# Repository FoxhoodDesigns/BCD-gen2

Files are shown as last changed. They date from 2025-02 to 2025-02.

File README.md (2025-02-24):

# Binary Clock 2
A successor to my very first electronics project i made when I was 16y old: A Binary Clock using only discrete logic (4000/74HC series)
Re-imagined using the skills I learned over time to turn it from a barely working beginner's project. To something I honestly could sell as a Soldering Kit.
Complete with fully worked out Power design that can safely be run off a Li-Ion Battery.

For more information. Please visit the Hackaday IO journal that is being written alongside this project that goes into depth on the reverse engineering of the original and iterating on its design:
https://hackaday.io/project/197273-4000-series-bcd-clock-g2

# NOTE ON PCB Layout:
This project is designed to be a little more artistic in appearance with the PCB visible to the outside world.
As such the PCB is intended to be made using a transparent Solder-mask that renders the copper visible. With the Front side lacking a Copper-pour and using rounded traces.
Please refer to OSH-Park's "After Dark" service for examples on how such PCBs tend to look.

# Current Status:
Still in mid Layout. Though should be ready for having its first set built once I finish it. Trying to figure out what to do with the Blank spot on the front in regards of copper. Maybe A Image of some kind?

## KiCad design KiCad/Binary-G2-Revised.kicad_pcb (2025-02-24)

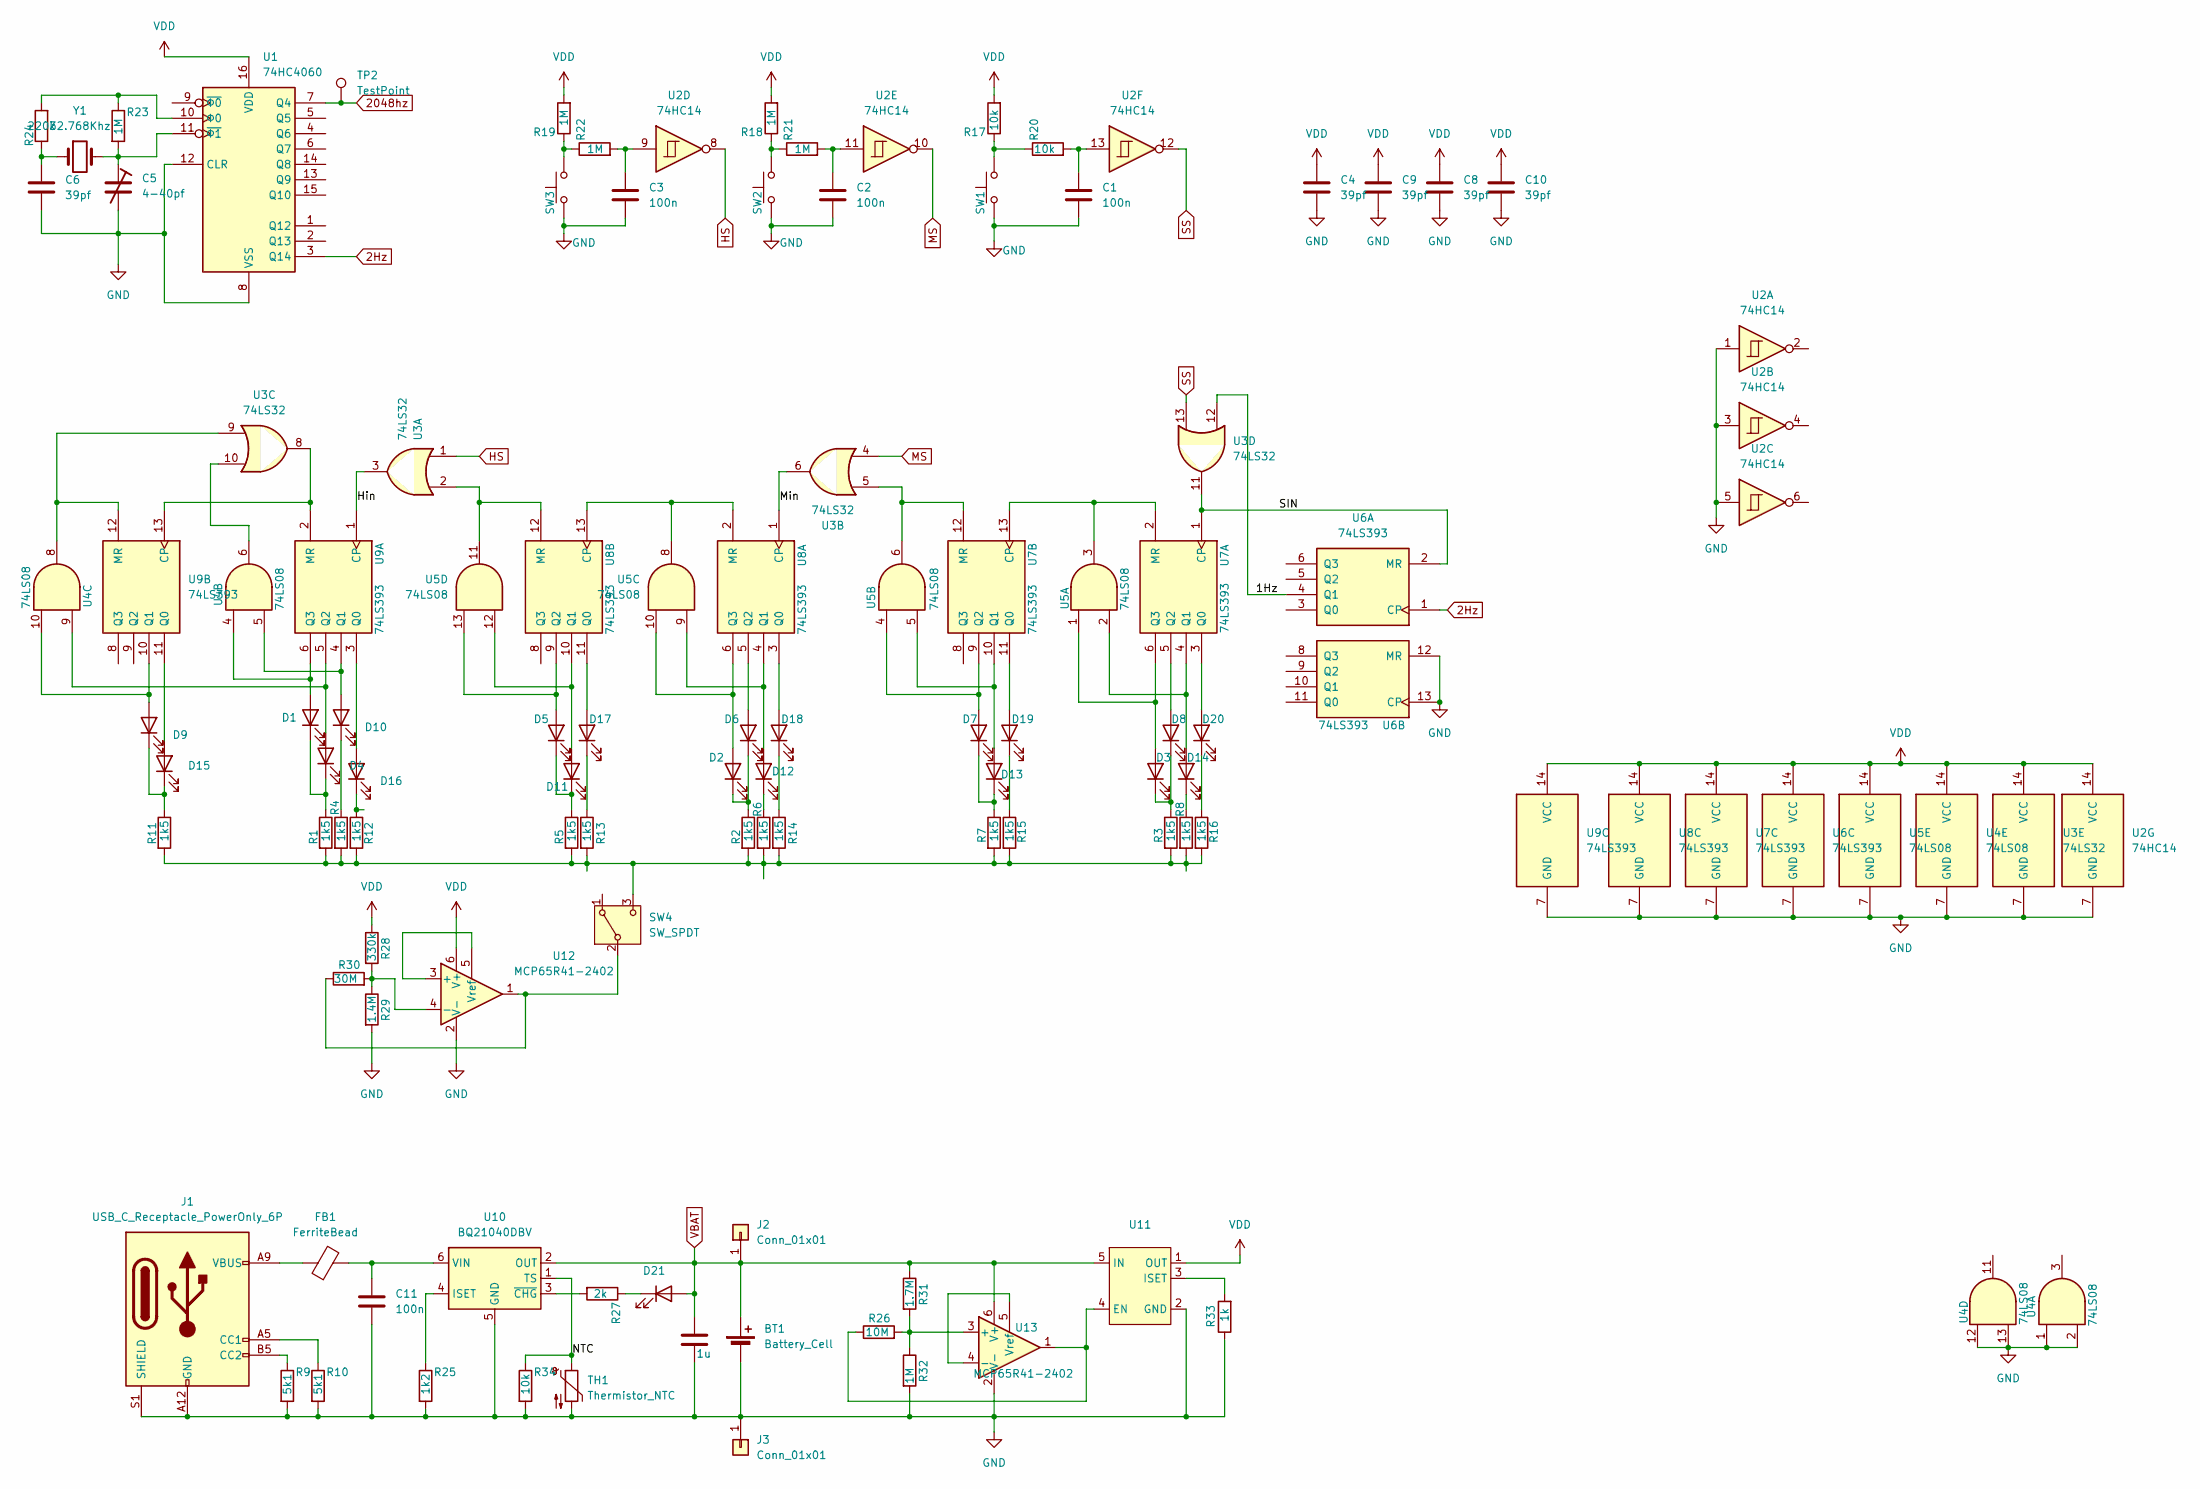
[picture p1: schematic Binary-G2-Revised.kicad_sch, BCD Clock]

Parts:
BT1: Battery_Cell
C1, C2, C3, C11: 100n; C_0805_2012Metric_Pad1.18x1.45mm_HandSolder
C4, C6, C8, C9, C10: 39pf; C_0805_2012Metric_Pad1.18x1.45mm_HandSolder
C5: 4-40pf; C_Trimmer_Murata_TZY2
C7: 1u; C_0805_2012Metric_Pad1.18x1.45mm_HandSolder
D1, D2, D3, D4, D5, D6, D7, D8, D9, D10, D11, D12, D13, D14, D15, D16, D17, D18, D19, D20: LED; LED_1206_3216Metric_Pad1.42x1.75mm_HandSolder
D21: LED; LED_0805_2012Metric_Pad1.15x1.40mm_HandSolder
FB1: FerriteBead; L_0805_2012Metric_Pad1.15x1.40mm_HandSolder
J1: USB_C_Receptacle_PowerOnly_6P; USB_C_Receptacle_USB4130
J2, J3: Conn_01x01; SolderWirePad_1x01_SMD_1x2mm
R1, R2, R3, R4, R5, R6, R7, R8, R11, R12, R13, R14, R15, R16: 1k5; R_0805_2012Metric_Pad1.20x1.40mm_HandSolder
R9, R10: 5k1; R_0805_2012Metric_Pad1.20x1.40mm_HandSolder
R17, R20, R34: 10k; R_0805_2012Metric_Pad1.20x1.40mm_HandSolder
R18, R19, R21, R22, R23, R32: 1M; R_0805_2012Metric_Pad1.20x1.40mm_HandSolder
R24: 220k; R_0805_2012Metric_Pad1.20x1.40mm_HandSolder
R25: 1k2; R_0805_2012Metric_Pad1.20x1.40mm_HandSolder
R26: 10M; R_0805_2012Metric_Pad1.20x1.40mm_HandSolder
R27: 2k; R_0805_2012Metric_Pad1.20x1.40mm_HandSolder
R28: 330k; R_0805_2012Metric_Pad1.20x1.40mm_HandSolder
R29: 1.4M; R_0805_2012Metric_Pad1.20x1.40mm_HandSolder
R30: 30M; R_0805_2012Metric_Pad1.20x1.40mm_HandSolder
R31: 1.7M; R_0805_2012Metric_Pad1.20x1.40mm_HandSolder
R33: 1k; R_0805_2012Metric_Pad1.20x1.40mm_HandSolder
SW1, SW2, SW3: PTH_RA_7.4x4.3mm; SW_Push_1P1T_NO_Vertical_Wuerth_434133025816
SW4: SW_SPDT; SW_SPDT_PCM12
TH1: Thermistor_NTC; SolderWirePad_1x01_SMD_1x2mm
TP2: TestPoint; TestPoint_Pad_2.0x2.0mm
U1: 74HC4060; SO-16_3.9x9.9mm_P1.27mm
U2: 74HC14; SO-14_3.9x8.65mm_P1.27mm
U3: 74LS32; SO-14_3.9x8.65mm_P1.27mm
U4, U5: 74LS08; SO-14_3.9x8.65mm_P1.27mm
U6, U7, U8, U9: 74LS393; SO-14_3.9x8.65mm_P1.27mm
U10: BQ21040DBV; SOT-23-6
U11: SOT-23-5_HandSoldering
U12, U13: MCP65R41-2402; SOT-23-6
Y1: 32.768Khz; Crystal_C26-LF_D2.1mm_L6.5mm_Horizontal_1EP_style2

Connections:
2Hz: U1.3 (Q14), U6.1 (CP)
2048hz: TP2.1, U1.7 (Q4)
/1Hz: U3.12, U6.4 (Q1)
/Hin: U3.3, U9.1 (CP)
/Min: U3.6, U8.1 (CP)
/NTC: R34.1, TH1.1, U10.1 (TS)
/SIN: U3.11, U6.2 (MR), U7.1 (CP)
GND: BT1.2 (-), C1.2, C2.2, C3.2, C4.2, C5.2, C6.2, C7.2, C8.2, C9.2, C10.2, C11.2, J1.A12 (GND), J1.B12 (GND), J1.S1 (SHIELD), J3.1, R9.2, R10.2, R25.2, R29.2, R32.2, R33.1, R34.2, SW1.1, SW2.1, SW3.1, TH1.2, U1.8 (VSS), U1.12 (CLR), U2.1, U2.3, U2.5, U2.7 (GND), U3.7 (GND), U4.1, U4.2, U4.7 (GND), U4.12, U4.13, U5.7 (GND), U6.7 (GND), U6.12 (MR), U6.13 (CP), U7.7 (GND), U8.7 (GND), U9.7 (GND), U10.5 (GND), U11.2 (GND), U12.2 (V-), U13.2 (V-)
HS: U2.8, U3.1
MS: U2.10, U3.4
unnamed: C1.1, R20.2, U2.13
unnamed: C2.1, R21.2, U2.11
unnamed: C3.1, R22.2, U2.9
unnamed: C6.1, R24.1, Y1.1
unnamed: D1.2 (A), U4.4, U9.6 (Q3)
unnamed: D1.1 (K), D4.1 (K), R1.1
unnamed: D2.2 (A), U5.10, U8.6 (Q3)
unnamed: D2.1 (K), D6.1 (K), R2.1
unnamed: D3.2 (A), U5.1, U7.6 (Q3)
unnamed: D3.1 (K), D8.1 (K), R3.1
unnamed: D4.2 (A), U4.9, U9.5 (Q2)
unnamed: D5.2 (A), U5.13, U8.9 (Q2)
unnamed: D6.2 (A), U8.5 (Q2)
unnamed: D7.2 (A), U5.4, U7.9 (Q2)
unnamed: D8.2 (A), U7.5 (Q2)
unnamed: D9.2 (A), U4.10, U9.10 (Q1)
unnamed: D10.2 (A), U4.5, U9.4 (Q1)
unnamed: D10.1 (K), R4.1
unnamed: D11.2 (A), U5.12, U8.10 (Q1)
unnamed: D5.1 (K), D11.1 (K), R5.1
unnamed: D12.2 (A), U5.9, U8.4 (Q1)
unnamed: D12.1 (K), R6.1
unnamed: D13.2 (A), U5.5, U7.10 (Q1)
unnamed: D7.1 (K), D13.1 (K), R7.1
unnamed: D14.2 (A), U5.2, U7.4 (Q1)
unnamed: D14.1 (K), R8.1
unnamed: D15.2 (A), U9.11 (Q0)
unnamed: D9.1 (K), D15.1 (K), R11.1
unnamed: D16.2 (A), U9.3 (Q0)
unnamed: D16.1 (K), R12.1
unnamed: D17.2 (A), U8.11 (Q0)
unnamed: D17.1 (K), R13.1
unnamed: D18.2 (A), U8.3 (Q0)
unnamed: D18.1 (K), R14.1
unnamed: D19.2 (A), U7.11 (Q0)
unnamed: D19.1 (K), R15.1
unnamed: D20.2 (A), U7.3 (Q0)
unnamed: D20.1 (K), R16.1
unnamed: D21.1 (K), R27.1
unnamed: FB1.1, J1.A9 (VBUS), J1.B9 (VBUS)
unnamed: J1.A5 (CC1), R10.1
unnamed: J1.B5 (CC2), R9.1
unnamed: R17.1, R20.1, SW1.2
unnamed: R18.1, R21.1, SW2.2
unnamed: R19.1, R22.1, SW3.2
unnamed: R30.1, SW4.2 (B), U12.1
unnamed: R1.2, R2.2, R3.2, R4.2, R5.2, R6.2, R7.2, R8.2, R11.2, R12.2, R13.2, R14.2, R15.2, R16.2, SW4.3 (C)
unnamed: C5.1, R23.2, U1.11 (~Φ1), Y1.2
unnamed: R23.1, R24.2, U1.10 (Φ0)
unnamed: U3.10, U4.6
unnamed: U5.3, U7.2 (MR), U7.13 (CP)
unnamed: U3.5, U5.6, U7.12 (MR)
unnamed: U5.8, U8.2 (MR), U8.13 (CP)
unnamed: U3.2, U5.11, U8.12 (MR)
unnamed: U3.8, U9.2 (MR), U9.13 (CP)
unnamed: U3.9, U4.8, U9.12 (MR)
unnamed: R25.1, U10.4 (ISET)
unnamed: C11.1, FB1.2, U10.6 (VIN)
unnamed: R27.2, U10.3 (~CHG)
unnamed: R26.1, U11.4 (EN), U13.1
unnamed: R33.2, U11.3 (ISET)
unnamed: U12.3 (+), U12.5 (Vref)
unnamed: R28.2, R29.1, R30.2, U12.4 (-)
unnamed: R26.2, R31.2, R32.1, U13.3 (+)
unnamed: U13.4 (-), U13.5 (Vref)
SS: U2.12, U3.13
VBAT: BT1.1 (+), C7.1, D21.2 (A), J2.1, R31.1, U10.2 (OUT), U11.5 (IN), U13.6 (V+)
VDD: C4.1, C8.1, C9.1, C10.1, R17.2, R18.2, R19.2, R28.1, U1.16 (VDD), U2.14 (VCC), U3.14 (VCC), U4.14 (VCC), U5.14 (VCC), U6.14 (VCC), U7.14 (VCC), U8.14 (VCC), U9.14 (VCC), U11.1 (OUT), U12.6 (V+)

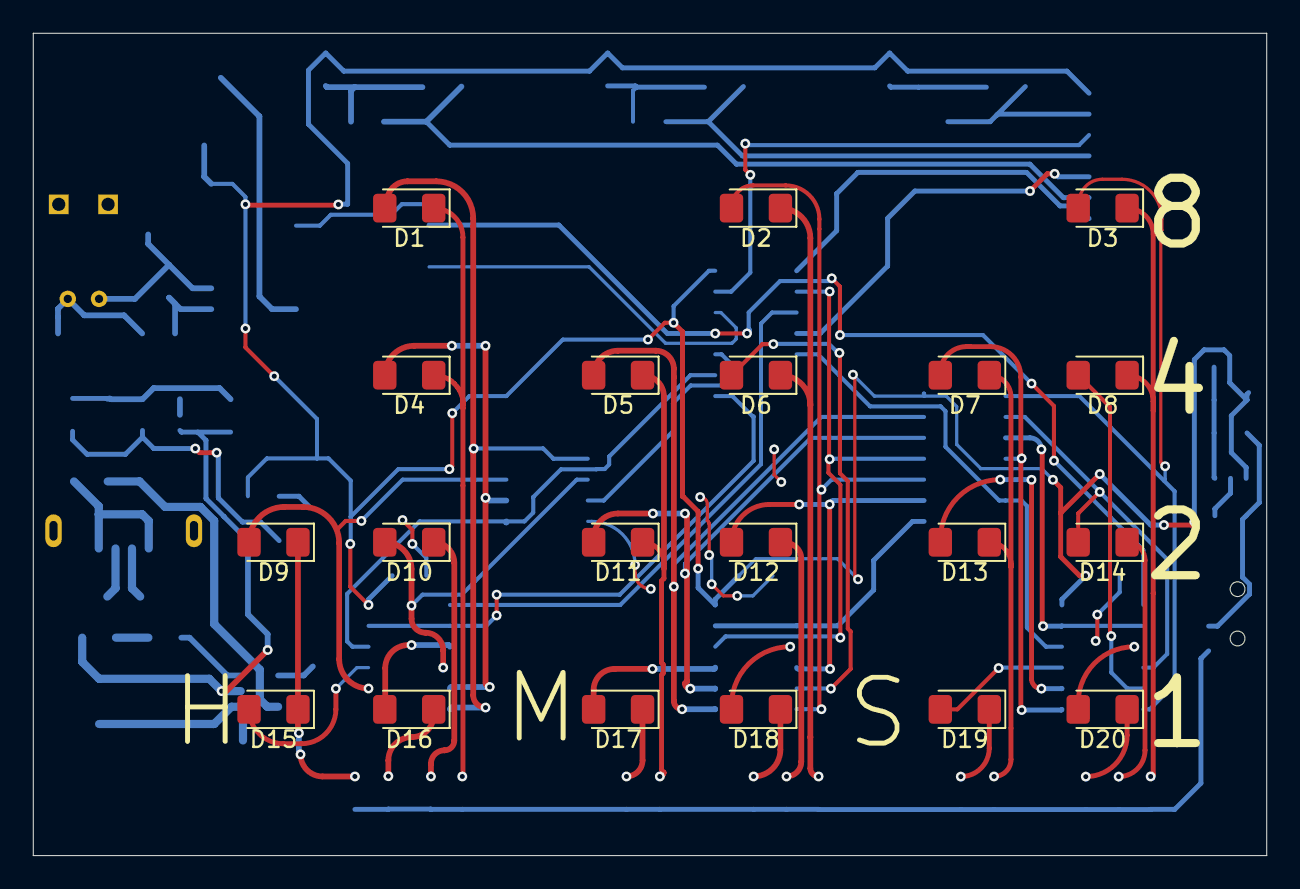
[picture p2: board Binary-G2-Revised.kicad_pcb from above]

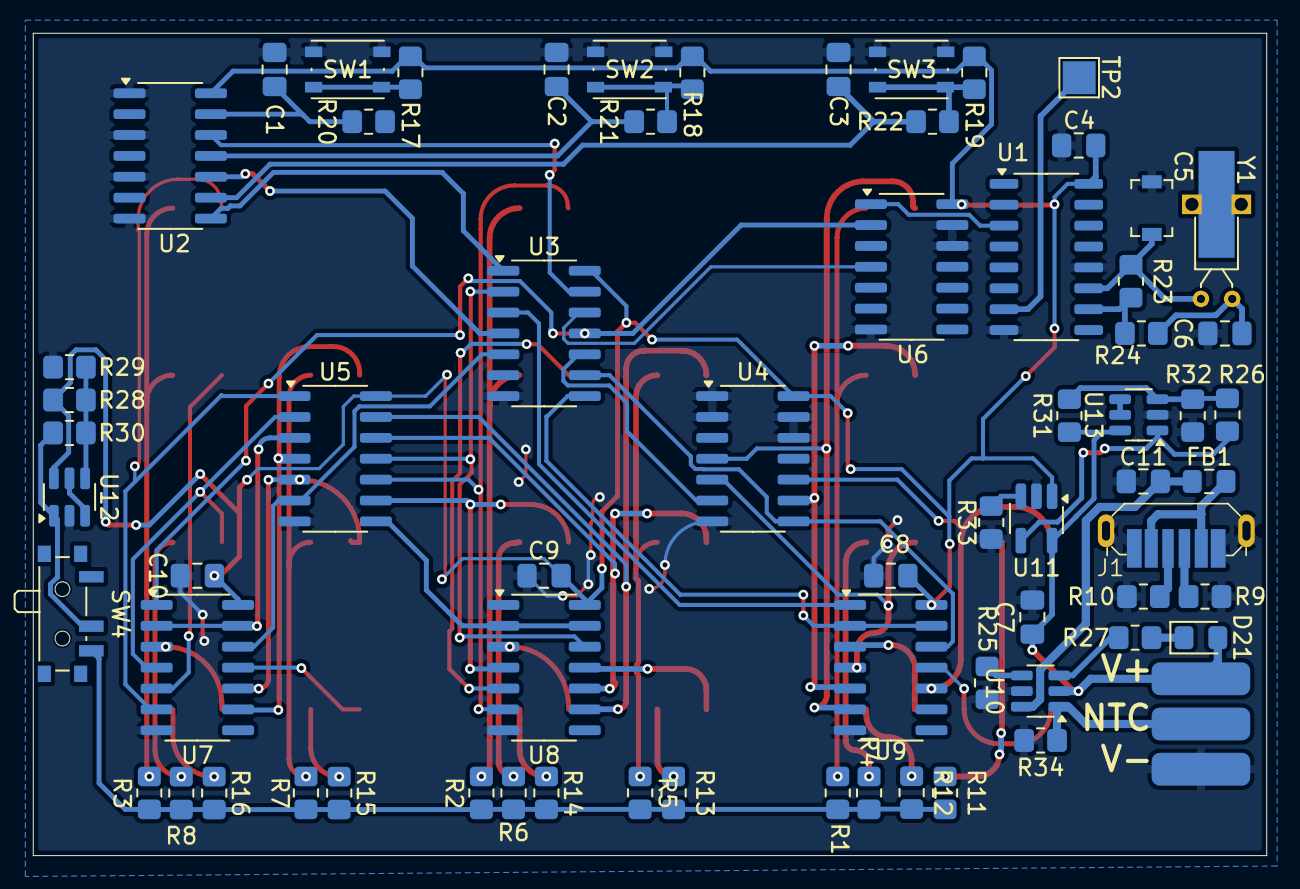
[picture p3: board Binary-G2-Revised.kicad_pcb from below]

Board: 2 copper layers, 75.0 x 50.0 mm, 90 parts (70 on the bottom side), 78 nets.

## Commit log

2025-02-24 Initial Upload
    [Binary-G2-Revised.kicad_pcb, Binary-G2-Revised.kicad_sch]
2025-02-24 Update with minimum layout
    Needs a lot more work.
    [Binary-G2-Revised.kicad_pcb, Binary-G2-Revised.kicad_sch]
2025-02-24 Quick Update Documentation
    [Binary-G2-Revised.kicad_pcb, Binary-G2-Revised.kicad_sch]
